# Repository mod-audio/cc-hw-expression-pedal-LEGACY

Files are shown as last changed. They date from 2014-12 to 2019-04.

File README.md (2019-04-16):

Legacy mod-hw-expression-pedal
=======================

This repository contains the schematics and PCB design files for the Expression Pedal hardware.
This is a peripheral meant to be used in conjunction with MOD (http://moddevices.com/) via its control-chain interface.

These files were created and can be improved with KiCAD, a free software Electronics CAD which is available at http://www.kicad-pcb.org/

## Check out instructions ##

This project uses a set of KiCAD symbols and footprints provided by the official KiCad library (https://github.com/KiCad/). In order to properly fetch these dependencies, which are configured as submodule repositories, you have to use the **--recursive** attribute in the following **git** command:

> git clone --recursive https://github.com/portalmod/mod-hw-expression-pedal.git

## Licensing ##

This is an Open Hardware project and all of the files in this repository are licensed under the terms of the "Creative Commons By-SA" license.

## Firmware ##

The firmware source code is freely available at https://github.com/portalmod/mod-fw-expression-pedal

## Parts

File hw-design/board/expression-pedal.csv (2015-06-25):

Item | Qty | Reference(s) | Value | LibPart | Footprint | Datasheet | MPN
1 | 1 | C1 | 10uF | device:CP1 | Capacitors_SMD:c_elec_5x5.3 |  | UWX1E100MCL1GB
2 | 1 | C10 | 10nF 500V | device:C | Capacitors_SMD:C_1206 |  | 501R18W103KV4E
3 | 2 | C11, C12 | 18pF | device:C | Capacitors_SMD:C_0603 |  | C1608C0G1H180J080AA
4 | 1 | C13 | 10nF | device:C | Capacitors_SMD:C_0603 |  | C1608X7R1E103K080AA
5 | 6 | C14, C15, C16, C17, C18, C9 | 100nF X7R | device:C | Capacitors_SMD:C_0603 |  | C1608X7R1E104K080AA
6 | 1 | C2 | 10uF | device:C | Capacitors_SMD:C_0805 |  | GRM219R61E106KA12D
7 | 4 | C3, C5, C6, C8 | 100nF | device:C | Capacitors_SMD:C_0603 |  | C1608X7R1E104K080AA
8 | 2 | C4, C7 | 100uF | device:CP1 | Capacitors_SMD:c_elec_6.3x5.3 |  | UWX1C101MCL1GB
9 | 1 | D1 | CGRA4007-G | device:D | Diodes_SMD:Diode-SMA_Standard |  | CGRA4007-G
10 | 2 | D2, D3 | 1N5819 | device:D_Schottky | Diodes_SMD:SOD-123 |  | 1N5819HW-7-F
11 | 1 | D4 | 1N4148 | device:D | Diodes_SMD:SOD-323 |  | 1N4148WX-TP
12 | 1 | D5 | LED_RGB | device:LED_RGB | LEDs:LED_RGB_PLLC-6 |  | LTRBGFSF-ABCB-QKYO-Z
13 | 1 | J1 | CC_INPUT | conn:RJ45_LEDS | Connect:RJHSE538X |  | RJHSE-5381
14 | 1 | J2 | CC_OUTPUT | conn:RJ45_LEDS | Connect:RJHSE538X |  | RJHSE-5381
15 | 1 | P1 | CHAIN | conn:CONN_01X04 | Pin_Headers:Pin_Header_Straight_1x04 |  | -
16 | 1 | P2 | USB_OTG | conn:USB_OTG | Connect:USB_Mini-B |  | 10033526-N3212LF
17 | 1 | P3 | SWD | conn:CONN_02X05 | Pin_Headers:Pin_Header_Straight_2x05_Pitch1.27mm |  | -
18 | 1 | P4 | FOOT | conn:CONN_01X02 | Pin_Headers:Pin_Header_Straight_1x02 |  | M20-9990246
19 | 1 | P5 | 10K POT | conn:CONN_01X03 | Pin_Headers:Pin_Header_Straight_1x03 |  | M20-9990346
20 | 4 | Q1, Q2, Q4, Q5 | 2N7002 | device:Q_NMOS_GSD | Housings_SOT-23_SOT-143_TSOT-6:SOT-23 |  | 2N7002P,215
21 | 1 | Q3 | FDN306P | device:Q_PMOS_GSD | local-footprints:SOT-23-fairchild |  | FDN306P_F095
22 | 1 | Q6 | IRFML8244TRPBF | device:Q_NMOS_GSD | Housings_SOT-23_SOT-143_TSOT-6:SOT-23 |  | IRFML8244TRPBF
23 | 1 | Q7 | BC857 | device:Q_PNP_BEC | Housings_SOT-23_SOT-143_TSOT-6:SOT-23 |  | BC857B,215
24 | 1 | R1 | 3K6 | device:R | Resistors_SMD:R_0603 |  | RMCF0603JT3K60
25 | 11 | R10, R11, R13, R22, R26, R3, R30, R31, R32, R4, R9 | 10k | device:R | Resistors_SMD:R_0603 |  | RMCF0603JT10K0
26 | 1 | R12 | 100R | device:R | Resistors_SMD:R_0805 |  | ERJ-P06F1000V
27 | 1 | R14 | 3k | device:R | Resistors_SMD:R_0603 |  | MCR03ERTF3001
28 | 1 | R15 | 24k | device:R | Resistors_SMD:R_0603 |  | MCR03ERTF2402
29 | 1 | R16 | 1k5 | device:R | Resistors_SMD:R_0603 |  | MCR03ERTF1501
30 | 1 | R17 | 1M | device:R | Resistors_SMD:R_0603 |  | RMCF0603JT1M00
31 | 2 | R18, R19 | 33R | device:R | Resistors_SMD:R_0603 |  | MCR03ERTF33R0
32 | 1 | R2 | 5K6 | device:R | Resistors_SMD:R_0603 |  | RMCF0603JT5K60
33 | 1 | R20 | 2K | device:R | Resistors_SMD:R_0603 |  | RMCF0603JT2K00
34 | 1 | R21 | 3K3 | device:R | Resistors_SMD:R_0603 |  | RMCF0603JT3K30
35 | 3 | R23, R24, R25 | 220R | device:R | Resistors_SMD:R_0603 |  | ESR03EZPJ221
36 | 3 | R27, R28, R29 | 100R | device:R | Resistors_SMD:R_0603 |  | RMCF0603JT100R
37 | 4 | R5, R6, R7, R8 | 820R | device:R | Resistors_SMD:R_0603 |  | ESR03EZPJ821
38 | 1 | RT1 | PTC_FUSE | device:FUSE | Resistors_SMD:R_1210 |  | 0ZCB0050FF2G
39 | 1 | SW1 | SW_PUSH | device:SW_PUSH | Buttons_Switches_SMD:SW_SPST_FSMSM |  | FSMSM
40 | 1 | SW2 | SP3T | device:SP3T | local-footprints:OS103011MA7QP1 |  | OS103011MA7QP1
41 | 1 | U1 | NCP1117DT50G | regul:NCP1117ST50T3G | SMD_Packages:DPAK-2 |  | NCP1117DT50G
42 | 1 | U2 | NCP1117DT33G | regul:NCP1117ST33T3G | SMD_Packages:DPAK-2 |  | NCP1117DT33G
43 | 1 | U3 | ISL83491 | interface:ISL83491 | Housings_SOIC:SOIC-14_3.9x8.7mm_Pitch1.27mm |  | ISL83491IBZ
44 | 1 | U4 | LPC11U24FBD48/401 | nxp_armmcu:LPC11U24FBD48/401 | Housings_QFP:LQFP-80_12x12mm_Pitch0.5mm |  | LPC11U24FBD48/401
45 | 1 | Y1 | 12MHz | device:Crystal_Small | Crystals:Crystal_HC49-SD_SMD |  | FOXSDLF/120-20

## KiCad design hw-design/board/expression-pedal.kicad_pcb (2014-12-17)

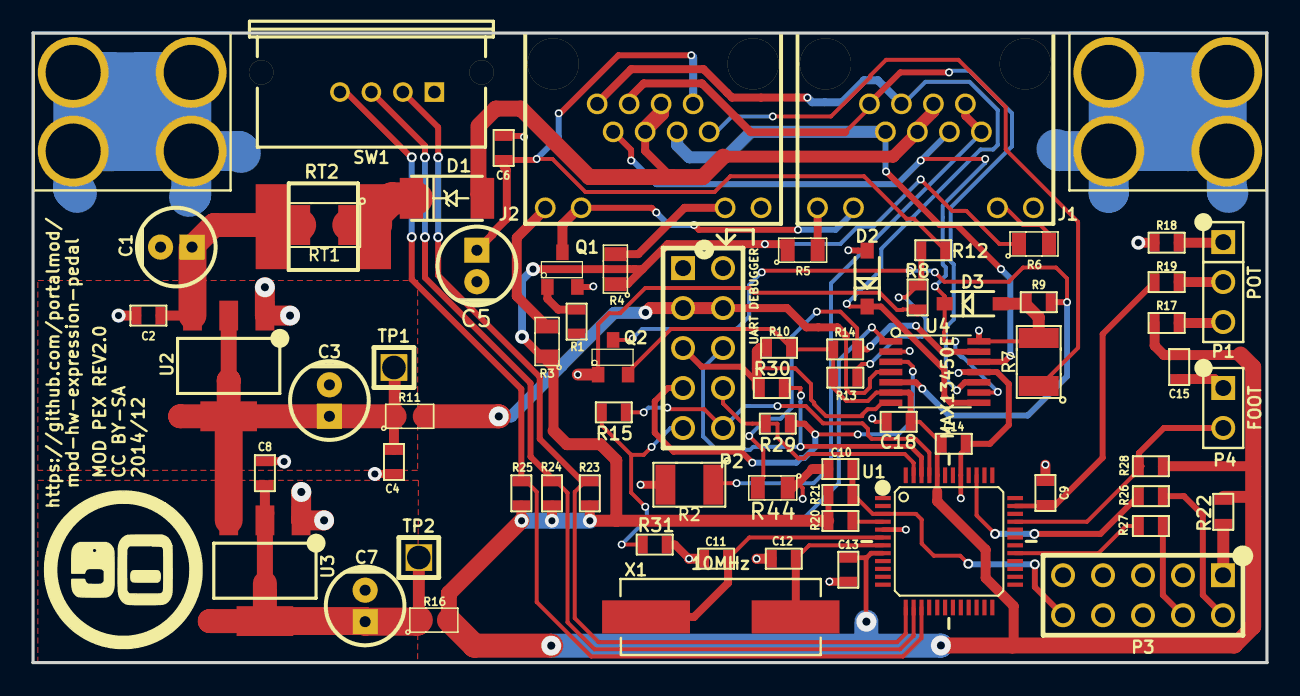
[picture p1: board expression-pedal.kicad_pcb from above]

Board: 2 copper layers, 78.4 x 40.0 mm, 71 parts (0 on the bottom side), 48 nets.

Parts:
C1, C3, C5, C7: 100uF; CAP_RAD_5MM
C2, C4, C6, C8, C9, C10, C13, C14, C15, C18: 100nF_X7R; SM0603
C11, C12: 18pF_NP0; SM0603
CN1, CN2: CONN_PANNEL_2X2; CONN_PANNEL
D1: CGRA4007-G; DO-214AC(SMA)
D2, D3: MMSZ5242B; SOD123
J1: RJ45_CHAIN_MAIN; RJ45-RJHSE5084
J2: RJ45_CHAIN_EXTENSION; RJ45-RJHSE5084
P1: HEADER_3X1; PIN_ARRAY_3X1
P2, P3: HEADER_5X2; PIN_ARRAY_5x2
P4: HEADER_2X1; PIN_ARRAY_2X1
Q1: MMBT3904; SOT23
Q2: MMBT3906; SOT23
R1, R8: 1k; SM0603
R2, R7: 100R 0.5W; SM1210
R3, R4, R5, R6: 470R; SM0805
R9, R10, R13, R14, R20, R21, R23, R24, R25, R28, R31: 10k; SM0603
R11, R16: 0R; SM0805
R12: 100k; SM0603
R15, R22, R29, R30: 0R; SM0603
R17, R18, R19, R26, R27: 100R; SM0603
R44: 0R/NC; SM0805
RT1: PTC_FUSE; SM1210
RT2: PTC_FUSE; SM2920
SW1: SWITCH_HH; SWITCH_HH_SK-13D26-G-6_5-K-GY
TP1, TP2: CONN_1; SIL-1
U1: LPC111X_LQFP48; LQFP48
U2: AP1117E50G; SOT223_3
U3: AP1117E33G; SOT223_3
U4: MAX13450E; TSSOP14
X1: 10MHz; HC_49US

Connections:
+3.3V: C13.1, C14.1, C15.1, C18.1, Q2.2, R3.1, R4.1, R5.1, R6.1, R10.1, R13.1, R14.1, R16.2, R17.2, R20.1, R21.1, R22.1, R23.1, R24.1, R25.1, R28.1, U1.8, U1.44, U4.6
+5V: P2.3, P2.4, R11.2, U4.4
+9V: C1.1, C2.1, RT1.2, RT2.2, U2.3
DGND: C1.2, C2.2, C3.2, C4.2, C5.2, C6.2, C7.2, C8.2, C9.2, C10.2, C11.1, C12.1, C13.2, C14.2, C15.2, C18.2, CN1.1, CN2.1, D2.1, D3.1, J1.12, J2.12, P2.1, P2.2, P3.3, P3.5, P3.7, P3.9, P4.1, Q1.2, R2.2, R7.2, R9.2, R18.2, R31.2, R44.1, SW1.1, U1.5, U1.41, U2.1, U3.1, U4.2, U4.11, U4.14
ENABLE_CHAIN: P2.9, R15.1, R31.1, U4.1
FOOT: P4.2, R28.2, U1.33
unnamed: C3.1, C4.1, R11.1, TP1.1, U2.2, U2.4, U3.3
unnamed: C5.1, C6.1, J2.7, R12.1
unnamed: C7.1, C8.1, R16.1, TP2.1, U3.2, U3.4
unnamed: C11.2, U1.6, X1.2
unnamed: C12.2, U1.7, X1.1
unnamed: D1.2, RT1.1, RT2.1
unnamed: J1.7, J1.8, R2.1
unnamed: J1.9, R5.2
unnamed: J1.10, J2.10, Q1.3
unnamed: J1.11, R6.2
unnamed: J2.8, R7.1
unnamed: J2.9, R3.2
unnamed: J2.11, R4.2
unnamed: P1.1, R18.1
unnamed: P1.2, R19.1
unnamed: P1.3, R17.1
unnamed: P2.6, R30.2, U1.46
unnamed: P2.8, R29.2, U1.47
unnamed: P2.10, R15.2, U1.45
unnamed: P3.1, R22.2
unnamed: P3.2, R26.2
unnamed: P3.4, R27.2
unnamed: Q1.1, R1.2
unnamed: Q2.1, R8.2
unnamed: R8.1, R12.2, R13.2
unnamed: R14.2, R44.2, U4.13
unnamed: R20.2, U1.4
POT: C9.1, R19.2, U1.35
RESET: C10.1, P3.10, R21.2, U1.3
RS485_RX+: D2.2, J1.3, J2.1, U4.8
RS485_RX-: D3.2, J1.6, J2.2, U4.9
RS485_TX+: J1.1, J2.3, U4.10
RS485_TX-: J1.2, J2.6, U4.12
RTERM_CHAIN: Q2.3, R9.1, U4.5
RX_CHAIN: P2.5, R10.2, R30.1, U4.7
SW1: R23.2, SW1.2, U1.13
SW2: R24.2, SW1.3, U1.14
SW3: R25.2, SW1.4, U1.15
SWDCLK: R27.1, U1.29
SWDIO: R26.1, U1.39
TX_CHAIN: P2.7, R29.1, U4.3
VCC: D1.1, J1.4, J1.5, J2.4, J2.5

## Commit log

2014-05-15 Initial commit of MOD PEX (MOD Expression Pedal) hardware project.
    [BOM_Mod_PEX_Prototype1.xls, MOD_PEX_Prototype1.kicad_pcb, MOD_PEX_Prototype1.sch]
2014-06-03 BOM for ITEAD quotes.
    [BOM_MOD_PEX_Prototpe1.xls, BOM_MOD_PEX_Prototpe1_2014.06.03.xls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]
2014-06-16 Created BOM with ITEAD template.
    [BOM_MOD_PEX_Prototpe1.xls, BOM_MOD_PEX_Prototpe1_Template_ITEAD_2014.06.16.xls, MOD_PEX_Prototype1.csv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]
2014-12-01 Adding metadata to the schematics drawing (fix issue #5) and improving the PCB grounding by attaching CN1 and CN2 to the DGND copper plane (fix issue #4).
    [MOD_PEX_Prototype1.kicad_pcb, MOD_PEX_Prototype1.sch]
2014-12-03 updating gerber files
    [MOD_PEX_Prototype1-B_Cu.gbl, MOD_PEX_Prototype1-B_Mask.gbs, MOD_PEX_Prototype1-B_SilkS.gbo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]
2014-12-03 removing spare ITEAD directory (which contained redundant copies of gerber files)
    [MOD_PEX_Prototype1-B_Cu.gbl, MOD_PEX_Prototype1-B_Mask.gbs, MOD_PEX_Prototype1-B_SilkS.gbo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]
2014-12-03 updating netlist and kicad_pcb
    [MOD_PEX_Prototype1-B_Cu.gbl, MOD_PEX_Prototype1-B_Mask.gbs, MOD_PEX_Prototype1-B_SilkS.gbo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]
2014-12-03 adding mod-kicad-footprints as a git submodule (and documenting it in the README)
2014-12-03 updating footprints (to use the ones from the mod-kicad-footprints repository)
    [MOD_PEX_Prototype1.kicad_pcb, MOD_PEX_Prototype1.sch]
2014-12-03 updating Gerbers
    [MOD_PEX_Prototype1-B_Cu.gbl, MOD_PEX_Prototype1-B_Mask.gbs, MOD_PEX_Prototype1-B_SilkS.gbo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]
2014-12-05 Bringing back the positioning of references and values that were messed up by the recent refactoring of footprint libraries.
    [MOD_PEX_Prototype1-B_Cu.gbl, MOD_PEX_Prototype1-B_Mask.gbs, MOD_PEX_Prototype1-B_SilkS.gbo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]
2014-12-09 wip on issue #7: protect the U4 IC when the board is being debugged Made the necessary changes in the schematics drawing.
    [MOD_PEX_Prototype1.sch]
2014-12-09 fix issue #7: protect the U4 IC when the board is being debugged updated the pcb traces and Gerber outputs.
    [MOD_PEX_Prototype1-B_Cu.gbl, MOD_PEX_Prototype1-B_Mask.gbs, MOD_PEX_Prototype1-B_SilkS.gbo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]
2014-12-09 wip on issue #9: change footprint of RT1 I'm adding a second footprint so that we have 2 choices of fuse packages we can use: SM2920 or SM1210
    [MOD_PEX_Prototype1.sch]
2014-12-09 fix issue #9: change footprint of RT1 (updated pcb traces and gerber outputs)
    [MOD_PEX_Prototype1-B_Cu.gbl, MOD_PEX_Prototype1-B_Mask.gbs, MOD_PEX_Prototype1-B_SilkS.gbo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]
2014-12-09 fix issue #3: Add "CC by-SA" license logo to the PCB silk layer I have adapted and rearranged the previous silk text as well.
    [MOD_PEX_Prototype1-B_Cu.gbl, MOD_PEX_Prototype1-B_Mask.gbs, MOD_PEX_Prototype1-B_SilkS.gbo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]
2014-12-12 wip on issue #11: Use the same control chain circuit of the footswitch separated the schematics in subsheets and added the new control chain circuit and schematic symbols
    [CPU.sch, Control_Chain.sch, MOD_PEX_Prototype1.sch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]
2014-12-12 wip issue #11: tracing the PCB signals
    [MOD_PEX_Prototype1.kicad_pcb]
2014-12-15 Fixing control chain signal names, adding a 0R resistor for the ENABLE_CHAIN signal in the P1 debugging connector and regenerating the netlist.
    [CPU.sch, Control_Chain.sch, MOD_PEX_Prototype1.sch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]
2014-12-15 fix issue #11 (new control chain circuitry): tracing the PCB to incorporate schematics changes.
    [CPU.sch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]
2014-12-15 fixing footprint and labels positioning.
    [MOD_PEX_Prototype1-B_Cu.gbl, MOD_PEX_Prototype1-B_Mask.gbs, MOD_PEX_Prototype1-B_SilkS.gbo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]
2014-12-15 updating a few 3d model settings
    [MOD_PEX_Prototype1.kicad_pcb]
2014-12-16 Adding a local copy of a few 3d models of components and using the TQFP48 one. Also fixing the references to the 3d models from the kicad-common deb-package.
    [MOD_PEX_Prototype1.kicad_pcb]
2014-12-16 fixing the component packages for SMD resistors (3d modules)
    [MOD_PEX_Prototype1.kicad_pcb]
2014-12-17 wip issue #12: Use 3.3V for Lv in the control chain circuit
    [CPU.sch, Control_Chain.sch]
2014-12-17 fix issue #12: Use 3.3V for Lv in the control chain circuit (updated the pcb layout and regenerated gerber files)
    [MOD_PEX_Prototype1-B_Cu.gbl, MOD_PEX_Prototype1-B_Mask.gbs, MOD_PEX_Prototype1-B_SilkS.gbo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]
2014-12-18 plotting the schematics to a PDF to be kept in the Docs directory (we should always update this PDF when we make changes to the schematics).
2015-01-07 Moving schematics component symbols to an external git submodule.
2015-01-07 Moving the Docs directory to the root dir of the repository.
    [BOM_MOD_PEX_Prototpe1.xls, MOD_PEX_Prototype1.csv]
2015-01-12 removing unused libraries
    [CPU.sch, Control_Chain.sch, MOD_PEX_Prototype1.sch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]
2015-01-12 renaming control chain sheet
    [MOD_PEX_Prototype1.sch, control-chain.sch]
2015-01-12 updating control chain circuit
    [CPU.sch, Power.sch, control-chain.sch]
2015-01-30 renaming project
    [BOM_MOD_PEX_Prototpe1.xls, BOM_MOD_PEX_Prototpe1_2014.06.03.xls, BOM_MOD_PEX_Prototpe1_Template_ITEAD_2014.06.16.xls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]
2015-01-30 moving I/O stuff to new sheet
    [CPU.sch, Power.sch, control-chain.sch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]
2015-02-07 renaming sch files
    [cpu.sch, expression-pedal.sch, power.sch]
2015-02-17 changing cpu schematic to use default kicad components library
    [cpu.sch]
2015-02-18 changing I/O schematic to use default kicad components library
    [io.sch]
2015-02-18 changing power schematic to use default kicad components library
    [power.sch]
2015-02-18 changing control chain schematic to use default kicad components library
    [control-chain.sch]
2015-02-18 adding libraries
    [cpu.sch, expression-pedal.sch, io.sch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]
2015-02-18 ERC passing
    [control-chain.sch, cpu.sch, io.sch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]
2015-02-19 removing one of the fuses
    [power.sch]
2015-02-27 wip: footprint association using default kicad libraries
    [control-chain.sch, cpu.sch, io.sch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]
2015-06-03 adding official kicad library as submodule
    [control-chain.sch, cpu.sch, io.sch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]
2015-06-03 replacing some cached symbols by kicad-library symbols
    [cpu.sch, power.sch]
2015-06-03 sch: updating some cached symbols
    [control-chain.sch, cpu.sch, expression-pedal.sch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]
2015-06-03 moving files inside board dir
    [control-chain.sch, cpu.sch, expression-pedal.kicad_pcb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]
2015-06-09 sch: load switch circuit sketch
    [power.sch]
2015-06-09 sch: updating local library
    [expression-pedal.sch]
2015-06-09 sch: control chain circuit (wip)
    [control-chain.sch]
2015-06-10 sch: control chain circuit
    [control-chain.sch]
2015-06-10 power circuit done
    [power.sch]
2015-06-10 sch: cpu reset done (wip)
    [cpu.sch]
2015-06-11 sch: cpu, I/Os and control chain circuits done
    [control-chain.sch, cpu.sch, io.sch]
2015-06-11 sch: schematic annotation done
    [control-chain.sch, cpu.sch, io.sch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]
2015-06-11 sch: errors fixed, DRC passing
    [control-chain.sch, cpu.sch, io.sch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]
2015-06-11 sch: adding values and MPN to components
    [control-chain.sch, cpu.sch, io.sch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]
2015-06-11 sch: BOM created
    [expression-pedal.csv]
2015-06-11 sch: JTAG connector footprint fixed
    [cpu.sch, expression-pedal.csv]
2015-06-12 sch: MOSFET MPN fixed
    [control-chain.sch, expression-pedal.csv]
2015-06-23 sch: setting footprints and updating BOM
    [control-chain.sch, cpu.sch, expression-pedal.csv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]
2015-06-23 footprints dependencies added to submodules
2015-06-23 fixing some footprints assignment
    [control-chain.sch, cpu.sch, expression-pedal.csv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]
2015-06-25 sch: fixing VBUS signal and FS1 I/O
    [cpu.sch, io.sch]
2015-06-25 BOM updated
    [expression-pedal.csv]
